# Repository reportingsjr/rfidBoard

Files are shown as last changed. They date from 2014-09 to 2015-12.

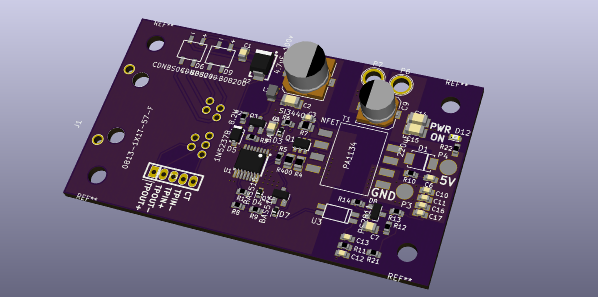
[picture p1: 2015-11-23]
hardware/POEstamp/POEstamp_3d_tilt.png

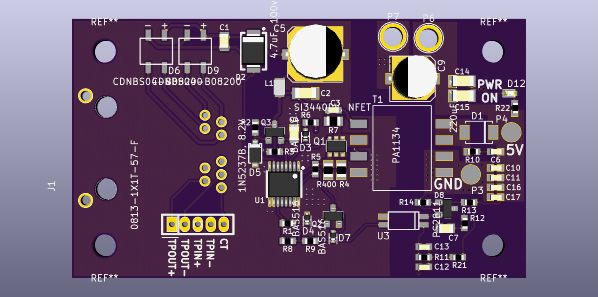
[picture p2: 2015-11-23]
hardware/POEstamp/POEstamp_3d_flat.png

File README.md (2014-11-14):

General
=========
This repository has the source for a PCB that uses Power over Ethernet (PoE) to power an STM32F103 microcontroller. It has a 10mbit ethernet MAC/PHY and  3.3V (.6A, 2W) and 12V (.5A, 6W) supplies fed from a 5V (1.8A, 9W) power rail. This gives this board the capability to provide power and control for quite a few different peripherals. The first use of the circuit boards and software in this repository is to provide a lower cost and more versatile RFID based entry method for a local hackerspace, Hive13.

In this repository you will currently find two main sections: hardware, and software. The hardware section contains the KiCad files for the PoE (power over ethernet)/micro board and the rfid transceiver board (rfidBoad). The software section contains the software/firmware for the stm32f103 to support the wanted functionality (currently ethernet comms and rfid/access control).
RFID/NFC board with ethernet+PoE with numerous I/Os.

Hardware
=========

The hardware consists of two separate boards: rfidBoard and PoE. rfidBoard is simply an rfid transceiver and antenna. PoE has an STM32F103 microcontroller which is connected to a 10mbit ethernet MAC/PHY. It alsohas a power over ethernet supply that provides 5V@1.8A total. This 5 volt supply provides power for a 3.3V supply and a 12V supply. The 3.3V supply is meant for powering ICs and other electronics while the 12V supply is meant for providing power to electronic door latches (solenoids).

rfid antenna
ST Micro's antenna.exe (can be found with google) was used to calculate the antenna size for an approximately 430nH antenna. A similar antenna of different shapes can be created by using the equations in the paper "Simple Accurate Expressions for Planar Spiral Inductances" (DOI 10.1109/4.792620). The parameters I used in antenna.exe are as follows: 2 turns, 8 segments, 1mm wide conductor, 0.25mm spacing between conductors, 35um conductor thickness, and 40mm by 40mm width and length.

Software
========
There is no software or firmware set up or written yet!
It will consist of a TCP/IP stack, an RFID stack, and a user access stack.

programs needed for compilation on fedora:
sudo yum install arm-none-eabi-gcc-cs arm-none-eabi-newlib scons

To program the board an STLINK v2 programmer is needed as well as stlink (on linux).

When cloning from git cd in to software/libopencm3 and run:
`git submodule init`
`git submodule update`

To flash the board with gdb and an st-link device:
In a separate terminal run the st-link server `st-util -1`
In another terminal run `arm-none-eabi-gdb firmware.elf`
Then in gdb run `tar ext :4242`, `load`, and finally either `continue` or `run`.

Datasheets
========
The datasheets directory contains some datasheets for different chips on board.
Currently it only contains STM32 microcontroller stuff.
They are large and don't fit well in to a git repository, but it helps keep
everything together and makes things easier to investigate down the line.

Notes and Issues
=========
* TODO: Add fuses on to POE board to protect circuitry.
* Several of the components in the PoE circuitry get WAY too hot.
* C5 (4.7uF cap on the PoE input) should have the negative pin connected to  GNDA/Pout rather than VPortN.
* ~~The 12V power supply current rating pretty much maxes out what the PoE can theoretically supply. Probably should derate the 12V supply quite a lot. This means that the 3.3V, 5V, and 12V will interfere with each other which is bad.~~ Updated current rating to 500mA which provides an ok margin for total power.
* ~~D1 may need to be unidirectional. The part specified in the BOM is currently bidirectional.~~ D1 should be a schottky!
* D2 is actually a zener, not a schottky as currently shown.
* *The footprint for U1 (LTC4267) is undersized.*

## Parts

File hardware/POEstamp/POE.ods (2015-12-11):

Reference | Value | Footprint | Datasheet | Vend1 | Vend1Id
U1 | LTC4267-3 | IPC7351-Nominal:SOP63P600X175-16 | https://cds.linear.com/docs/en/datasheet/4267fc.pdf | Digikey | LTC4267CGN-3#PBF-ND
C5 | 4.7uF, 100v | rfid:EEE-2AA4R7UP | http://media.digikey.com/pdf/Data%20Sheets/Panasonic%20Capacitors%20PDFs/EEE_S_A.pdf | Digikey | PCE3972CT-ND
C1 | 0.1uF, 100V, x7r | IPC7351-Nominal:CAPC2012X95 | https://media.digikey.com/pdf/Data%20Sheets/Samsung%20PDFs/CL21B104KCC5PNC_Spec.pdf | digikey | 1276-2447-1-ND
L1 | 3.3uH | IPC7351-Nominal:INDC2012X130 | https://product.tdk.com/info/en/catalog/datasheets/inductor_commercial_decoupling_mlz2012_en.pdf | Digikey | 445-6394-1-ND | FBMH1608HM601-T
C2 | 1uF, 100v | IPC7351-Nominal:CAPC3216X180 | http://ds.yuden.co.jp/TYCOMPAS/ut/detail.do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 | Digikey | 587-1777-1-ND
C4 | 4.7uF, 10v | IPC7351-Nominal:CAPC2012X135 | http://www.samsungsem.com/kr/support/product-search/mlcc/CL21A475KPFNNNE.jsp | Digikey | 1276-1259-1-ND | 490-3335-1-ND
D5 | 1N5237B, 8.2v | rfid:SOD-123 | http://www.diodes.com/_files/datasheets/ds18004.pdf | Digikey | BZT52C8V2-FDICT-ND
R2 | 220K | IPC7351-Nominal:RESC1608X55 | http://industrial.panasonic.com/www-cgi/jvcr13pz.cgi?E+PZ+3+AOA0002+ERJ3EKF2203V+7+WW | Digikey | P220KHCT-ND
R3 | 220K | IPC7351-Nominal:RESC1608X55 | http://industrial.panasonic.com/www-cgi/jvcr13pz.cgi?E+PZ+3+AOA0002+ERJ3EKF2203V+7+WW | Digikey | P220KHCT-ND
D3 | BAS516 | rfid:SOD-523 | http://www.nxp.com/documents/data_sheet/BAS16_SER.pdf | Digikey | 568-1603-1-ND
R6 | 510R | IPC7351-Nominal:RESC1608X55 | http://industrial.panasonic.com/www-cgi/jvcr13pz.cgi?E+PZ+3+AOA0002+ERJ3EKF5100V+7+WW | Digikey | P510HCT-ND
C3 | 68pF, 200v | IPC7351-Nominal:CAPC1608X87 | http://www.kemet.com/docfinder?Partnumber=C0603C680J2GACTU | Digikey | 399-10054-1-ND
R7 | 100R, 1/8w | IPC7351-Nominal:RESC2012X70 | http://industrial.panasonic.com/www-cgi/jvcr13pz.cgi?E+PZ+3+AOA0002+ERJ6ENF1000V+7+WW | Digikey | P100CCT-ND
T1 | PA1134 | rfid:PA1134 | http://productfinder.pulseeng.com/products/datasheets/SPM2007_55.pdf | Digikey | 553-1982-1-ND
R4 | 0.250R | IPC7351-Nominal:RESC2013X65 | http://www.seielect.com/catalog/SEI-CSR_CSRN.pdf | Digikey | CSR0805FKR250CT-ND
R400 | 0.250R | IPC7351-Nominal:RESC2013X65 | http://www.seielect.com/catalog/SEI-CSR_CSRN.pdf | Digikey | CSR0805FKR250CT-ND
R5 | 4.7K | IPC7351-Nominal:RESC1608X55 | http://www.te.com/commerce/DocumentDelivery/DDEController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 | Digikey | A106050CT-ND
D7 | BAS516 | rfid:SOD-523 | http://www.nxp.com/documents/data_sheet/BAS16_SER.pdf | Digikey | 568-1603-1-ND
D4 | BAS516 | rfid:SOD-523 | http://www.nxp.com/documents/data_sheet/BAS16_SER.pdf | Digikey | 568-1603-1-ND
R1 | 10k | IPC7351-Nominal:RESC1608X55 | http://industrial.panasonic.com/www-cgi/jvcr13pz.cgi?E+PZ+3+AOA0002+ERJ3EKF1002V+7+WW | Digikey | P10.0KHCT-ND
R8 | 100k | IPC7351-Nominal:RESC1608X55 | http://industrial.panasonic.com/www-cgi/jvcr13pz.cgi?E+PZ+3+AOA0002+ERJ3EKF1003V+7+WW | Digikey | P100KHCT-ND
R9 | 6.8k | IPC7351-Nominal:RESC1608X55 | http://industrial.panasonic.com/www-cgi/jvcr13pz.cgi?E+PZ+3+AOA0002+ERJ3EKF6801V+7+WW | Digikey | P6.80KHCT-ND
U3 | PS2811 | rfid:SSOP-4 | http://www.cel.com/pdf/datasheets/ps2811.pdf | Digikey | PS2811-1ACT-ND
D1 | PMEG3050EP | rfid:SOD-128 | http://www.nxp.com/documents/data_sheet/PMEG3050EP.pdf | Digikey | 568-6753-1-ND
R10 | 10R | IPC7351-Nominal:RESC1608X55 | http://industrial.panasonic.com/www-cgi/jvcr13pz.cgi?E+PZ+3+AOA0001+ERJ3GEYJ100V+7+WW | Digikey | P10GCT-ND
C6 | 470pF | IPC7351-Nominal:CAPC1608X90 | http://www.samsungsem.com/kr/support/product-search/mlcc/CL10B471KB8NNNC.jsp | Digikey | 1276-1094-1-ND
C14 | 100uF, 6.3v, x5r | IPC7351-Nominal:CAPC3216X180 | http://capacitoredge.kemet.com/capedge2/DataSheet?pn=C1206C107M9PACTU | Digikey | 399-5620-1-ND | CL31A107MQHNNNE
C9 | 220uF, 6.3v | rfid:EEE-FK0J221P | http://industrial.panasonic.com/www-cgi/jvcr13pz.cgi?E+PZ+3+ABA0120+EEEFK0J221P+7+WW | Digikey | PCE3766CT-ND
C15 | 100uF, 6.3v, x5r | IPC7351-Nominal:CAPC3216X180 | http://capacitoredge.kemet.com/capedge2/DataSheet?pn=C1206C107M9PACTU | Digikey | 399-5620-1-ND | CL31A107MQHNNNE
R14 | 33.2k | IPC7351-Nominal:RESC1608X55 | http://industrial.panasonic.com/www-cgi/jvcr13pz.cgi?E+PZ+3+AOA0002+ERJ3EKF3322V+7+WW | Digikey | P33.2KHCT-ND
R13 | 100k, 1% | IPC7351-Nominal:RESC1608X55 | http://industrial.panasonic.com/www-cgi/jvcr13pz.cgi?E+PZ+3+AOA0002+ERJ3EKF1003V+7+WW | Digikey | P100KHCT-ND
R11 | 1k | IPC7351-Nominal:RESC1608X55 | http://www.te.com/commerce/DocumentDelivery/DDEController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 | Digikey | A106049CT-ND
C12 | 1uF | IPC7351-Nominal:CAPC1608X90 | http://www.samsungsem.com/kr/support/product-search/mlcc/CL10F105ZP8NNNC.jsp | Digikey | 1276-1041-1-ND
C13 | 33nF | IPC7351-Nominal:CAPC1608X95 | https://product.tdk.com/info/en/catalog/spec/mlccspec_commercial_general_midvoltage_en.pdf | Digikey | 445-5093-1-ND
C7 | 27nF | IPC7351-Nominal:CAPC2012X88 | http://www.yageo.com/documents/recent/UPY-GPHC_X7R_6.3V-to-50V-v12.pdf | Digikey | 311-1139-1-ND | CL10B273KB8SFNC
R12 | 47k | IPC7351-Nominal:RESC1608X55 | http://industrial.panasonic.com/www-cgi/jvcr13pz.cgi?E+PZ+3+AOA0002+ERJ3EKF4702V+7+WW | Digikey | P47.0KHCT-ND
P4 | +5V | Measurement_Points:Measurement_Point_Round-SMD-Pad_Big
P3 | GND | Measurement_Points:Measurement_Point_Round-SMD-Pad_Big
J1 | 0813-1X1T-57-F | rfid:0813-1X1T-57-F | http://belfuse.com/pdfs/0813-1X1T-57-F.pdf | Digikey | 507-1421-ND
R22 | 2.8k | IPC7351-Nominal:RESC1608X55 | http://www.yageo.com/NewPortal/yageodocoutput?fileName=/pdf/R-Chip/PYu-RC_Group_51_RoHS_L_3.pdf | Digikey | 311-2.80KHRCT-ND
D8 | TLV431 | smd-semi:SOT-23 | http://www.diodes.com/_files/datasheets/TLV431.pdf | Digikey | TLV431AFTACT-ND
D9 | CDNBS04-B08200 | rfid:CDNBS04
D6 | CDNBS04-B08200 | rfid:CDNBS04 | http://www.bourns.com/docs/Product-Datasheets/CDNBS04-B08200_B08800.pdf | Digikey | CDNBS04-B08200CT-ND
Q1 | SI3440DV, NFET | rfid:TSOP-6 | http://www.vishay.com/docs/72380/72380.pdf | Digikey | SI3440DV-T1-E3CT-ND
D2 | SMAJ58A | IPC7351-Nominal:DIOM5436X265 | http://www.littelfuse.com/~/media/electronics/datasheets/tvs_diodes/littelfuse_tvs_diode_smaj_datasheet.pdf.pdf | Digikey | SMAJ58ALFCT-ND
C8 | 2.8nF, 250VAC, YCAP | IPC7351-Nominal:CAPC4532X150 | http://psearch.murata.com/capacitor/product/GA343QR7GD222KW01%23.pdf | Digikey | 490-3492-1-ND
C10 | 100nF | IPC7351-Nominal:CAPC1608X90 | http://www.yageo.com/documents/recent/UPY-GPHC_Y5V_6.3V-to-50V_5_revised.pdf | Digikey | 311-1343-1-ND
C11 | 100nF | IPC7351-Nominal:CAPC1608X90 | http://www.yageo.com/documents/recent/UPY-GPHC_Y5V_6.3V-to-50V_5_revised.pdf | Digikey | 311-1343-1-ND
C16 | 1uF | IPC7351-Nominal:CAPC1608X90 | http://search.murata.co.jp/Ceramy/image/img/A01X/G101/ENG/GRM188R61E105KA12-01.pdf | Digikey | 490-3897-1-ND
C17 | 1uF | IPC7351-Nominal:CAPC1608X90 | http://search.murata.co.jp/Ceramy/image/img/A01X/G101/ENG/GRM188R61E105KA12-01.pdf | Digikey | 490-3897-1-ND
Q3 | MMBTA42 | smd-semi:SOT-23 | http://www.diodes.com/_files/datasheets/ds30062.pdf | Digikey | MMBTA42-FDICT-ND
Q2 | 2N7002 | smd-semi:SOT-23 | http://www.diodes.com/_files/datasheets/ds11303.pdf | Digikey | 2N7002-FDICT-ND
P5 | CONN_01X05 | conn-2mm:CONN-2MM-F-1x5
P6 | 5Vout | Connect:1pin
P7 | GNDout | Connect:1pin
R21 | 470R | IPC7351-Nominal:RESC1608X55 | http://industrial.panasonic.com/www-cgi/jvcr13pz.cgi?E+PZ+3+AOA0002+ERJ3EKF4700V+7+WW | Digikey | P470HCT-ND
D12 | 5V LED | LEDs:LED-0603 | http://www.osram-os.com/Graphics/XPic9/00128783_0.pdf | Digikey | 475-1409-1-ND

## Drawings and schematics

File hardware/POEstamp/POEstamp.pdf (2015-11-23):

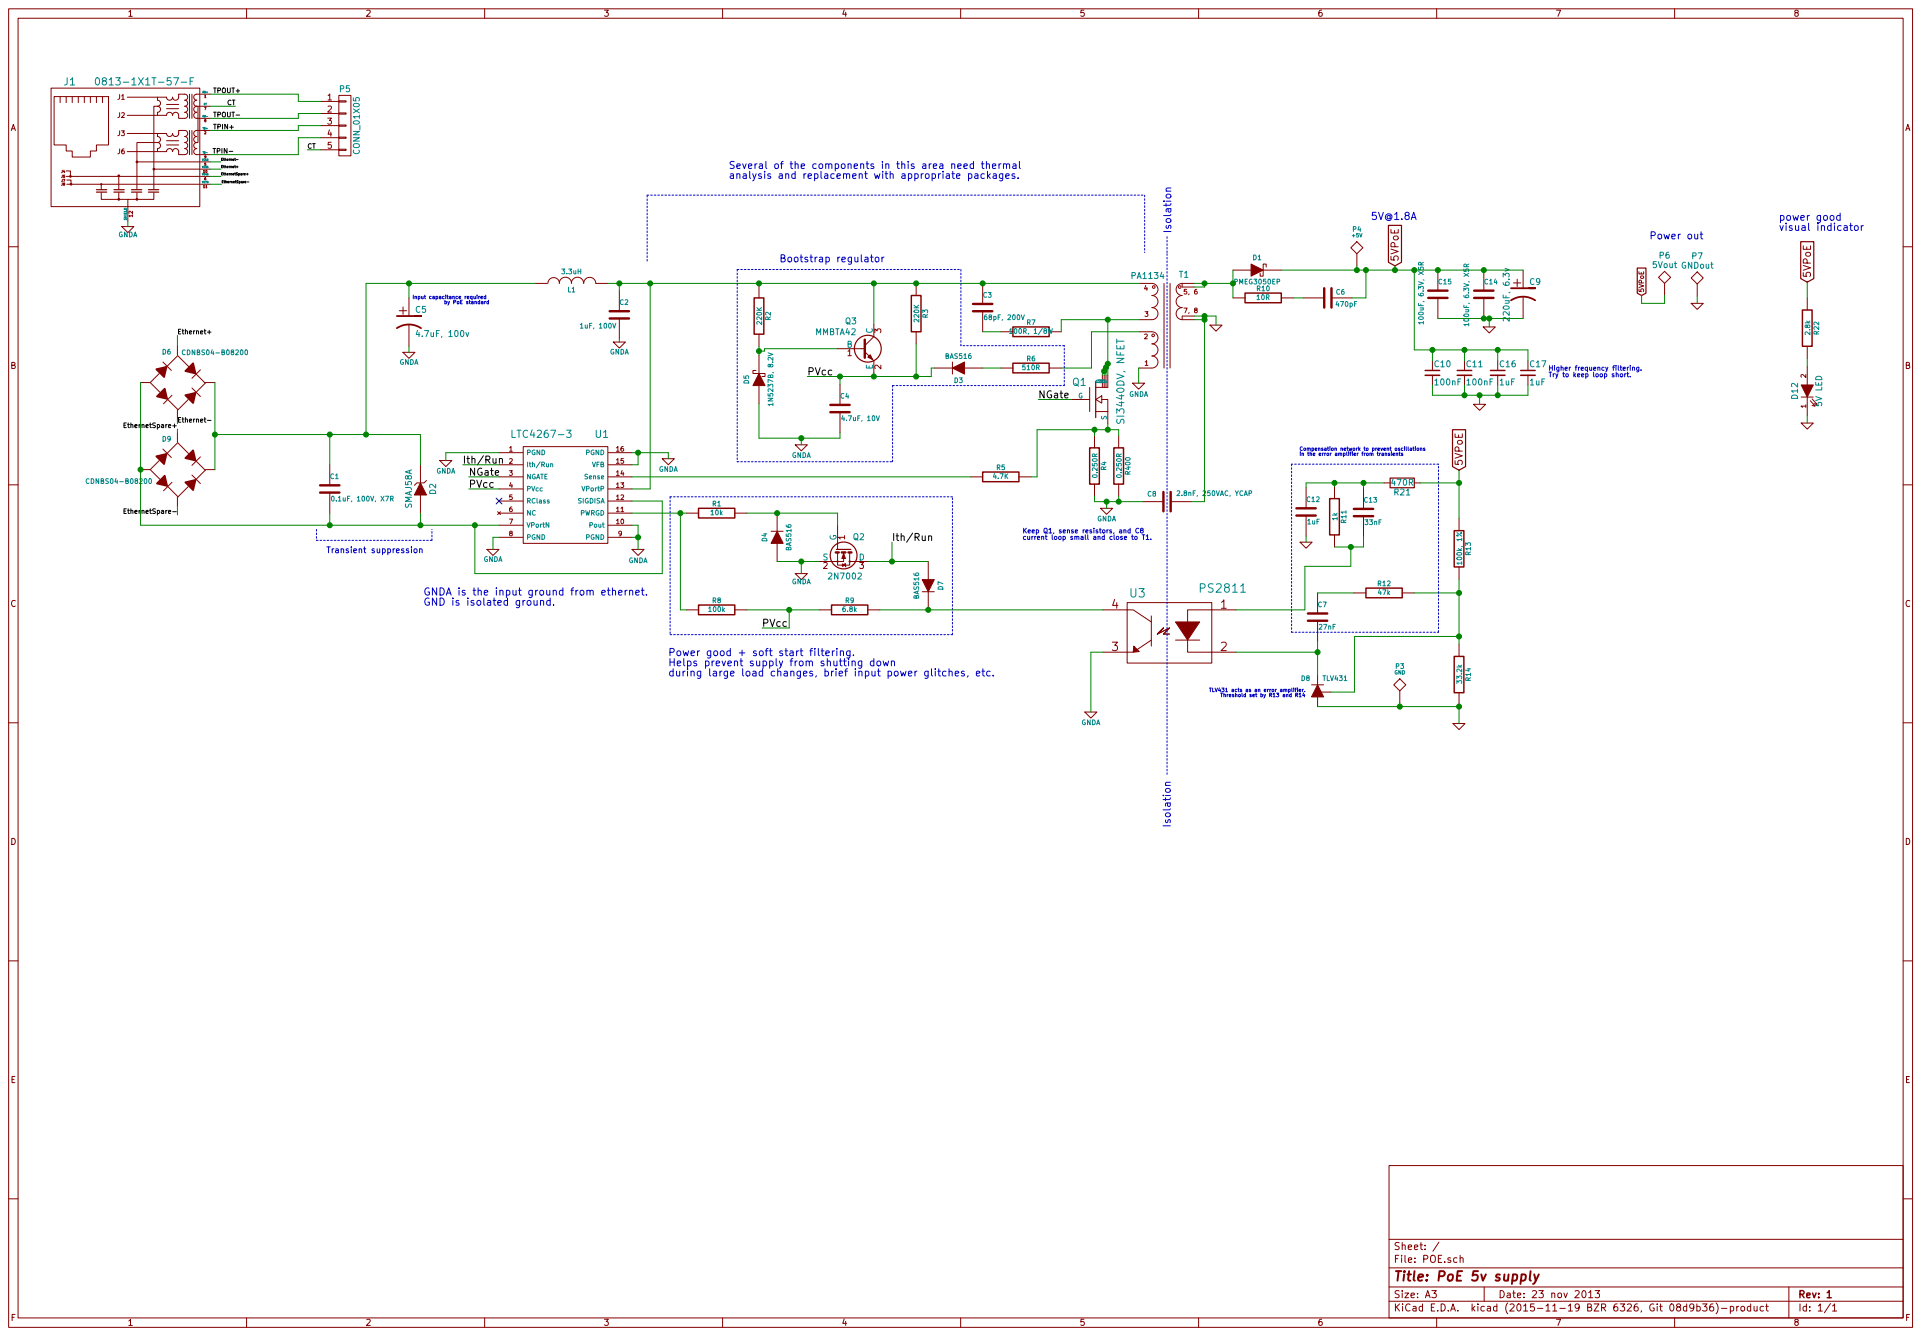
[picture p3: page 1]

470R Several of the components in this area need thermal

Input capacitance required by PoE standard

Higher frequency filtering. Try to keep loop short. B

in the error amplifier from transients Ith/Run

TLV431 acts as an error amplifier. Threshold set by R13 and R14Compensation network to prevent oscillations

Keep Q1, sense resistors, and C8 current loop small and close to T1. Power good + soft start filtering.

Helps prevent supply from shutting down

File: POE.sch Sheet: /
Id: 1/1 Title: PoE 5v supply

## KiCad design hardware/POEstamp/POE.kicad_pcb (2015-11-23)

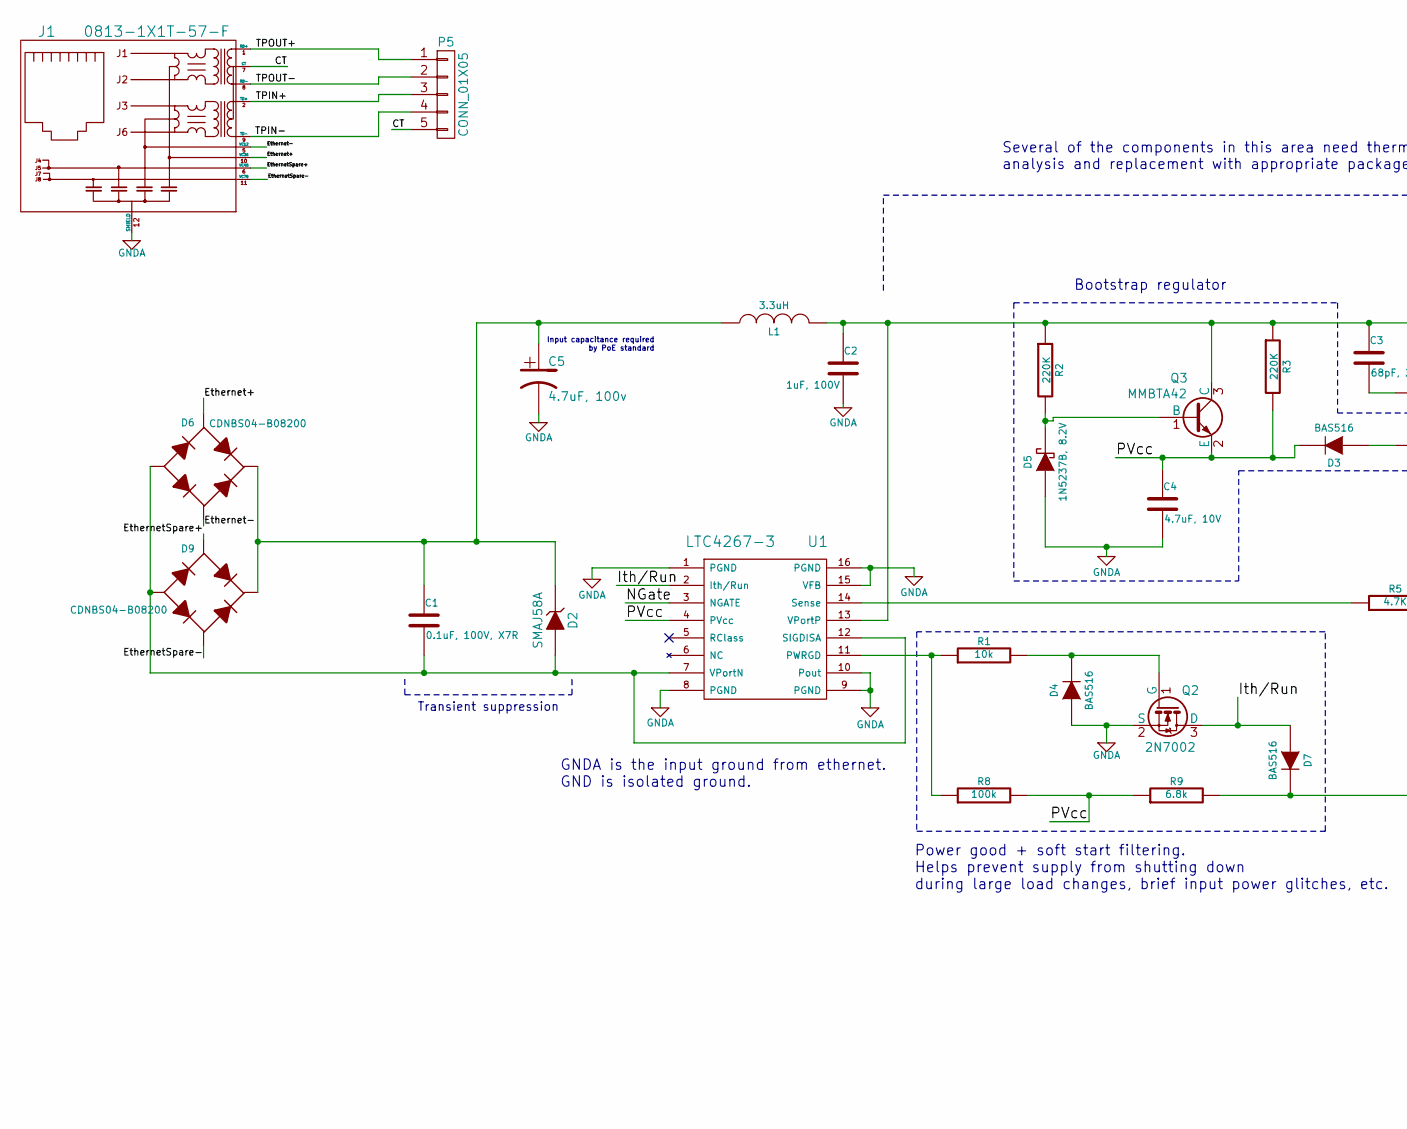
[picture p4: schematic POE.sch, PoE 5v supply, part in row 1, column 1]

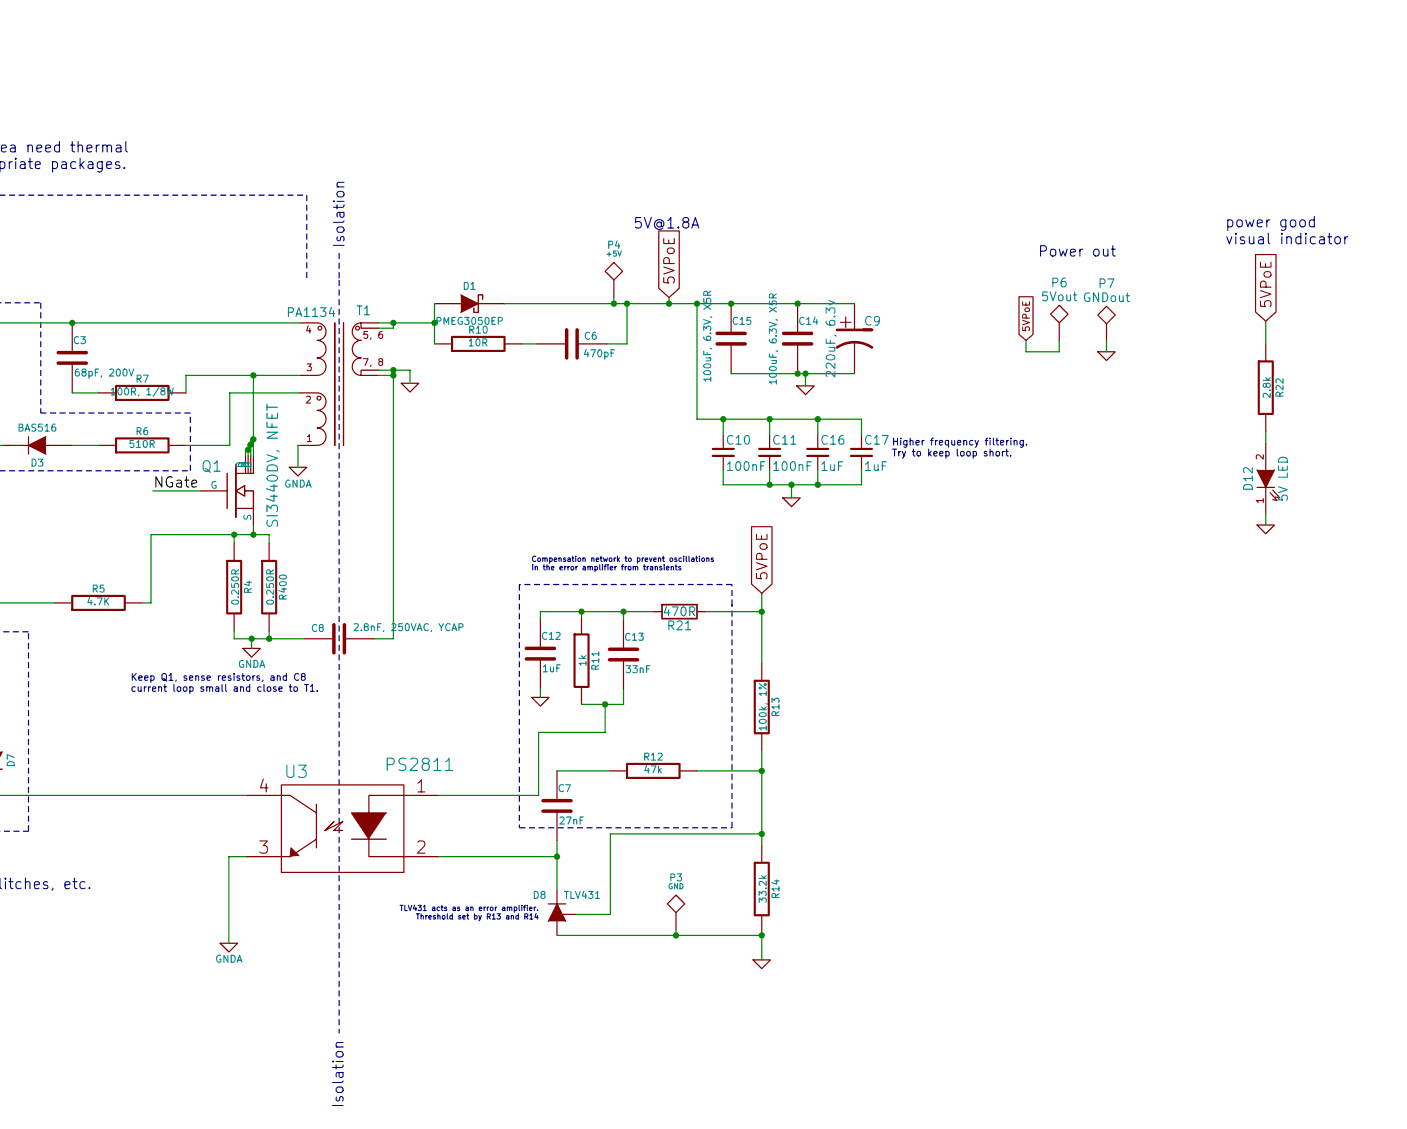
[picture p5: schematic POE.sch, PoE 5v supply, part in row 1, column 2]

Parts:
C1: 0.1uF, 100V, X7R; CAPC2012X95
C2: 1uF, 100V; CAPC3216X180
C3: 68pF, 200V; CAPC1608X87
C4: 4.7uF, 10V; CAPC2012X135
C5: 4.7uF, 100v; EEE-2AA4R7UP
C6: 470pF; CAPC1608X90
C7: 27nF; CAPC2012X88
C8: 2.8nF, 250VAC, YCAP; CAPC4532X150
C9: 220uF, 6.3v; EEE-FK0J221P
C10, C11: 100nF; CAPC1608X90
C12, C16, C17: 1uF; CAPC1608X90
C13: 33nF; CAPC1608X95
C14, C15: 100uF, 6.3V, X5R; CAPC3216X180
D1: PMEG3050EP; SOD-128
D2: SMAJ58A; DIOM5436X265
D3, D4, D7: BAS516; SOD-523
D5: 1N5237B, 8.2V; SOD-123
D6, D9: CDNBS04-B08200; CDNBS04
D8: TLV431; SOT-23
D12: 5V LED; LED-0603
J1: 0813-1X1T-57-F
L1: 3.3uH; INDC2012X130
P3: GND; Measurement_Point_Round-SMD-Pad_Big
P4: +5V; Measurement_Point_Round-SMD-Pad_Big
P5: CONN_01X05; CONN-2MM-F-1x5
P6: 5Vout; 1pin
P7: GNDout; 1pin
Q1: SI3440DV, NFET; TSOP-6
Q2: 2N7002; SOT-23
Q3: MMBTA42; SOT-23
R1: 10k; RESC1608X55
R2, R3: 220K; RESC1608X55
R4, R400: 0.250R; RESC2013X65
R5: 4.7K; RESC1608X55
R6: 510R; RESC1608X55
R7: 100R, 1/8W; RESC2012X70
R8: 100k; RESC1608X55
R9: 6.8k; RESC1608X55
R10: 10R; RESC1608X55
R11: 1k; RESC1608X55
R12: 47k; RESC1608X55
R13: 100k, 1%; RESC1608X55
R14: 33.2k; RESC1608X55
R21: 470R; RESC1608X55
R22: 2.8k; RESC1608X55
T1: PA1134
U1: LTC4267-3; SOP63P600X175-16
U3: PS2811; SSOP-4

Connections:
5VPoE: C6.1, C9.1, C10.1, C11.1, C14.1, C15.1, C16.1, C17.1, D1.2 (K), P4.1, P6.1, R13.1, R21.1, R22.1
/CT: J1.7 (CT), P5.5
/Ethernet+: D6.3, J1.10 (VC36)
/Ethernet-: D6.2, J1.5 (VC12)
/EthernetSpare+: D9.3, J1.6 (VC45)
/EthernetSpare-: D9.2, J1.11 (VC78)
/Ith/Run: D7.1 (A), Q2.3 (D), U1.2 (Ith/Run)
/NGate: Q1.3 (G), U1.3 (NGATE)
/PVcc: C4.1, D3.2 (K), Q3.2 (E), R3.2, R8.2, R9.1, U1.4 (PVcc)
/TPIN+: J1.2 (TD+), P5.3
/TPIN-: J1.9 (TD-), P5.4
/TPOUT+: J1.1 (RD+), P5.1
/TPOUT-: J1.8 (RD-), P5.2
GND: C8.1, C9.2, C10.2, C11.2, C12.2, C14.2, C15.2, C16.2, C17.2, D8.3 (A), D12.1 (K), P3.1, P7.1, R14.2, T1.7, T1.8
GNDA: C2.2, C4.2, C5.2, C8.2, D4.1 (A), D5.1 (A), J1.12 (SHIELD), Q2.2 (S), R4.2, R400.2, T1.1, U1.1 (PGND), U1.8 (PGND), U1.9 (PGND), U1.10 (Pout), U1.15 (VFB), U1.16 (PGND), U3.3
unnamed: C1.1, C5.1, D2.1 (K), D6.1 (+), D9.1 (+), L1.1
unnamed: C1.2, D2.2 (A), D6.4 (-), D9.4 (-), U1.7 (VPortN), U1.12 (SIGDISA)
unnamed: C2.1, C3.1, L1.2, Q3.3 (C), R2.1, R3.1, T1.4, U1.13 (VPortP)
unnamed: C3.2, R7.1
unnamed: C6.2, R10.2
unnamed: C7.1, R12.1
unnamed: C7.2, D8.2 (K), U3.2
unnamed: C12.1, C13.1, R11.1, R21.2
unnamed: C13.2, R11.2, U3.1
unnamed: D1.1 (A), R10.1, T1.5, T1.6
unnamed: D3.1 (A), R6.1
unnamed: D4.2 (K), Q2.1 (G), R1.2
unnamed: D5.2 (K), Q3.1 (B), R2.2
unnamed: D7.2 (K), R9.2, U3.4
unnamed: D8.1 (ref), R12.2, R13.2, R14.1
unnamed: D12.2 (A), R22.2
unnamed: Q1.1 (D), Q1.2 (D), Q1.5 (D), Q1.6 (D), R7.2, T1.3
unnamed: Q1.4 (S), R4.1, R5.2, R400.1
unnamed: R1.1, R8.1, U1.11 (PWRGD)
unnamed: R5.1, U1.14 (Sense)
unnamed: R6.2, T1.2

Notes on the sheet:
GNDA is the input ground from ethernet. GND is isolated ground.
5V@1.8A
power good visual indicator
Keep Q1, sense resistors, and C8 current loop small and close to T1.
Power good + soft start filtering. Helps prevent supply from shutting down during large load changes, brief input power glitches, etc.
Isolation
Transient suppression
Input capacitance required by PoE standard
TLV431 acts as an error amplifier. Threshold set by R13 and R14
Compensation network to prevent oscillations in the error amplifier from transients
Bootstrap regulator
Higher frequency filtering. Try to keep loop short.
Power out
Several of the components in this area need thermal analysis and replacement with appropriate packages.

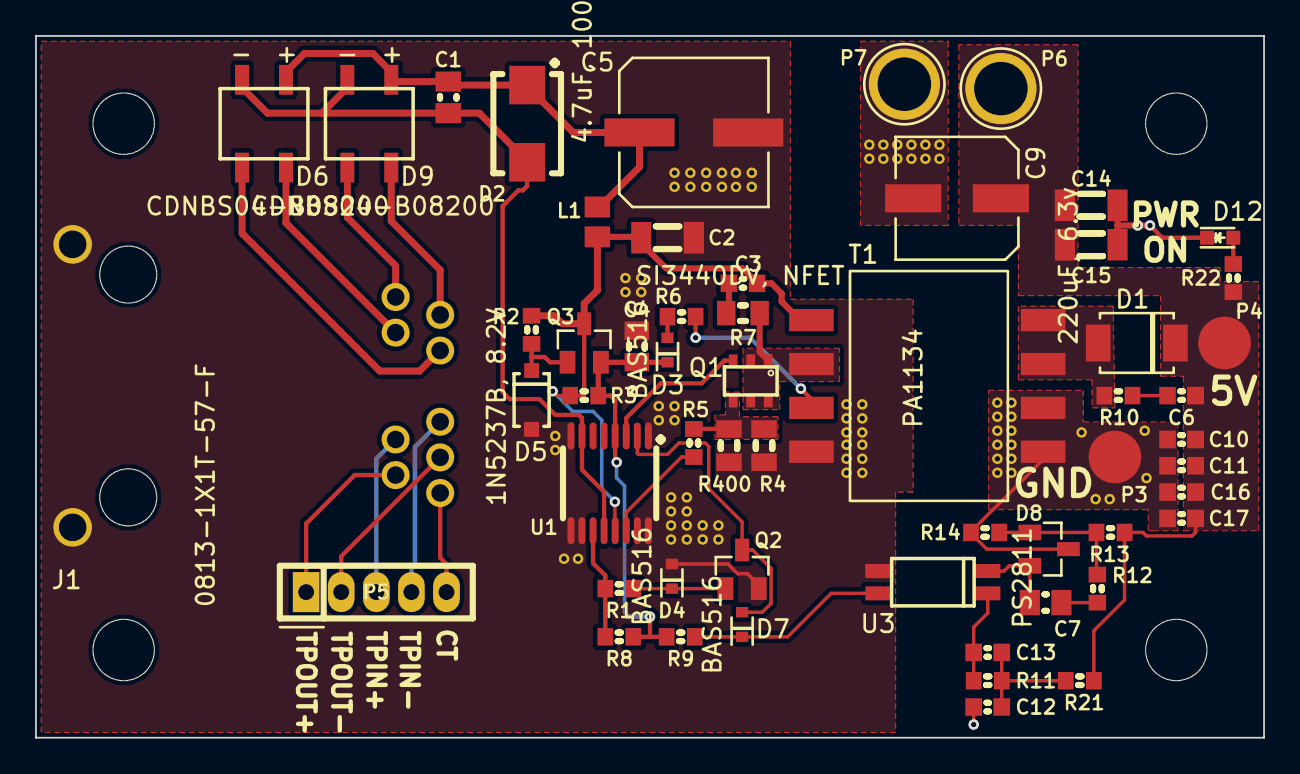
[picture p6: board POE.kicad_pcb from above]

Board: 2 copper layers, 70.0 x 40.0 mm, 57 parts (1 on the bottom side), 36 nets.

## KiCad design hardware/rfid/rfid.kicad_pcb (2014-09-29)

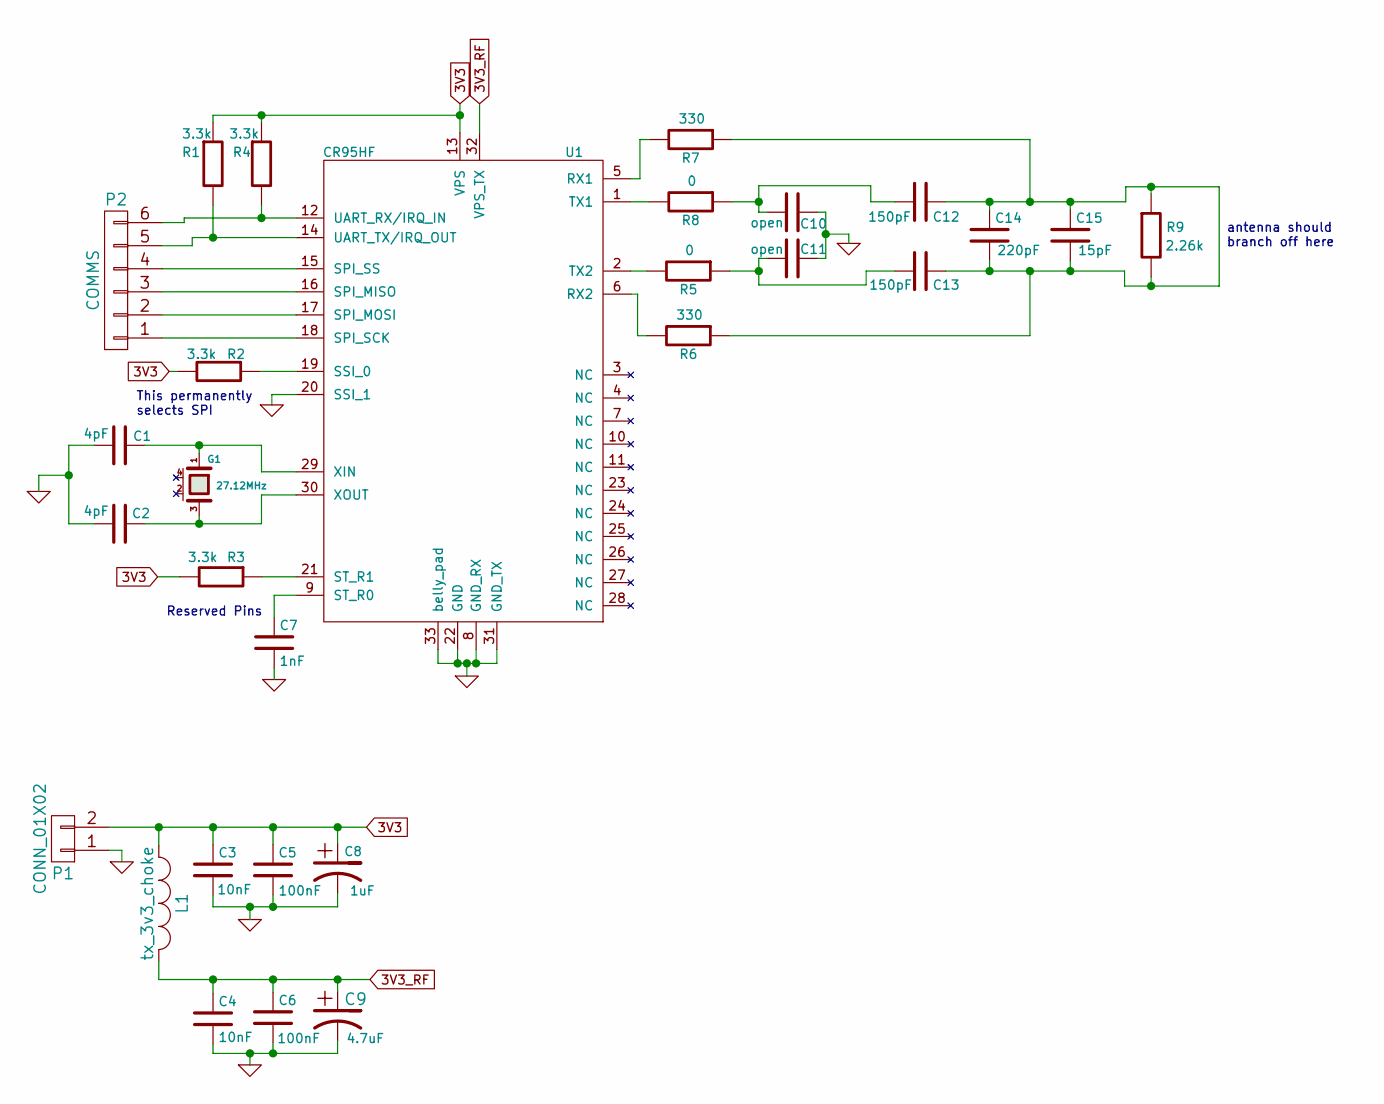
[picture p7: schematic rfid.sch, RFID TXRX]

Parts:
C1, C2: 4pF; SMD-0603
C3, C4: 10nF; SMD-0603
C5, C6: 100nF; SMD-0603
C7: 1nF; SMD-0603
C8: 1uF; SMD-0603
C9: 4.7uF; SMD-0805
C10, C11: open; SMD-0603
C12, C13: 150pF; SMD-0603
C14: 220pF; SMD-0603
C15: 15pF; SMD-0603
G1: 27.12MHz; 2x1.6_crystal
L1: tx_3v3_choke; SMD-0603
P1: CONN_01X02; JST_PH_2pin_side
P2: COMMS; JST_PH_6pin
R1, R2, R3, R4: 3.3k; SMD-0603
R5, R8: 0; SMD-0603
R6, R7: 330; SMD-0603
R9: 2.26k; SMD-0603
U1: CR95HF; QFN-32-1EP

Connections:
3V3: C3.1, C5.1, C8.1, L1.1, P1.2, R1.1, R2.2, R3.2, R4.1, U1.13 (VPS)
3V3_RF: C4.1, C6.1, C9.1, L1.2, U1.32 (VPS_TX)
GND: C1.2, C2.2, C3.2, C4.2, C5.2, C6.2, C7.2, C8.2, C9.2, C10.1, C11.1, P1.1, U1.8 (GND_RX), U1.20 (SSI_1), U1.22 (GND), U1.31 (GND_TX), U1.33 (belly_pad)
unnamed: C1.1, G1.1, U1.29 (XIN)
unnamed: C2.1, G1.3, U1.30 (XOUT)
unnamed: C7.1, U1.9 (ST_R0)
unnamed: C10.2, C12.2, R8.1
unnamed: C11.2, C13.2, R5.1
unnamed: C12.1, C13.1, C14.1, C14.2, C15.1, C15.2, R6.1, R7.1, R9.1, R9.2
unnamed: P2.1, U1.18 (SPI_SCK)
unnamed: P2.2, U1.17 (SPI_MOSI)
unnamed: P2.3, U1.16 (SPI_MISO)
unnamed: P2.4, U1.15 (SPI_SS)
unnamed: P2.5, R1.2, U1.14 (UART_TX/IRQ_OUT)
unnamed: P2.6, R4.2, U1.12 (UART_RX/IRQ_IN)
unnamed: R2.1, U1.19 (SSI_0)
unnamed: R3.1, U1.21 (ST_R1)
unnamed: R5.2, U1.2 (TX2)
unnamed: R6.2, U1.6 (RX2)
unnamed: R7.2, U1.5 (RX1)
unnamed: R8.2, U1.1 (TX1)

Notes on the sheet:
Reserved Pins
This permanently selects SPI
antenna should branch off here

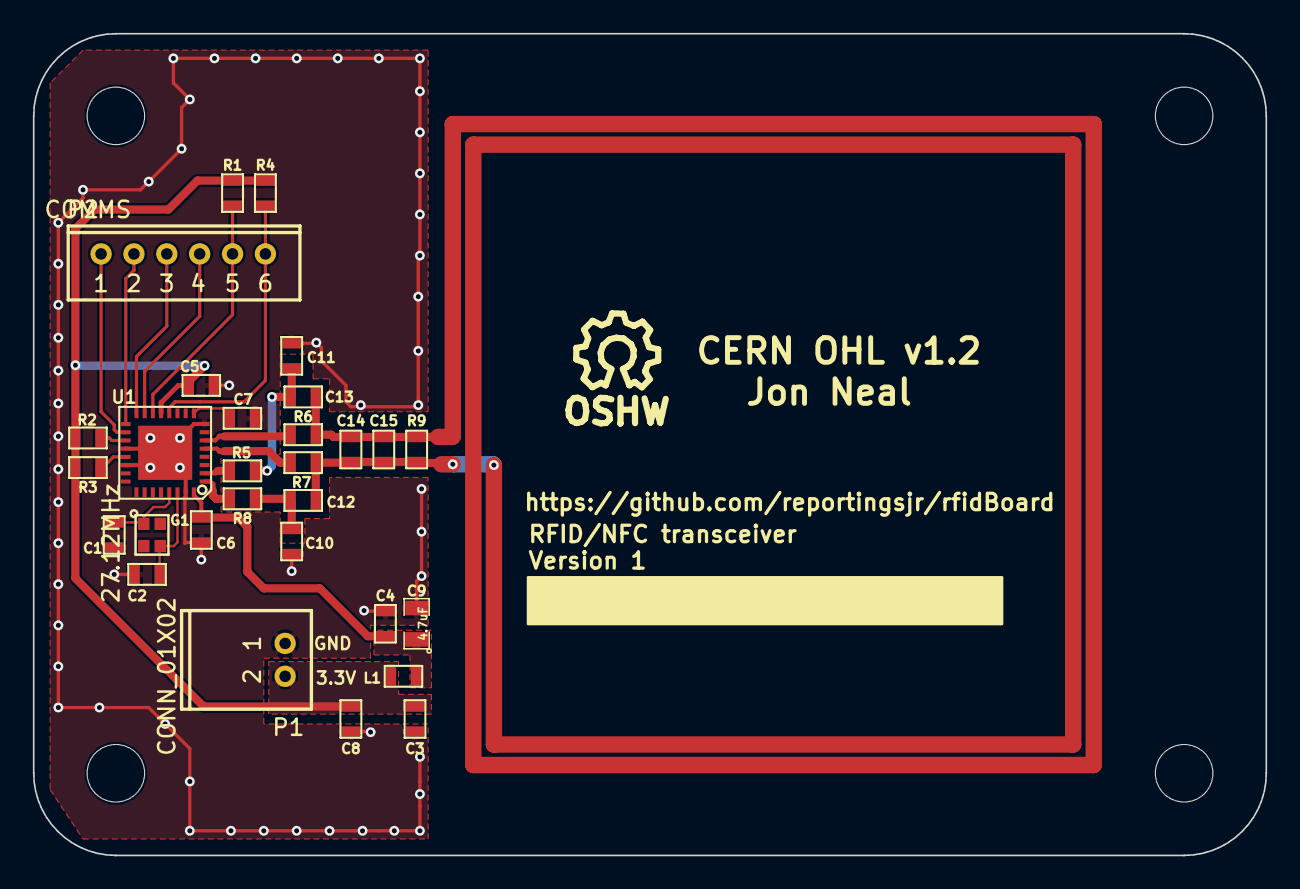
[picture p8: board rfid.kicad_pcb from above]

Board: 2 copper layers, 75.0 x 50.0 mm, 34 parts (0 on the bottom side), 21 nets.

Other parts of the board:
MH: MountingHole_3-5mm_RevA_Date21Jun2010; MountingHole_3-5mm
MH#2, MH#3, MH#4: MountingHole_3-5mm_RevA_Date21Jun2010; MountingHole_3-5mm
SYM: Symbol_OSHW-Logo_SilkScreen_07Jul2012; Symbol_OSHW-Logo_SilkScreen

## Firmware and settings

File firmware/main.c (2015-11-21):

/*
    ChibiOS/RT - Copyright (C) 2006-2013 Giovanni Di Sirio

    Licensed under the Apache License, Version 2.0 (the "License");
    you may not use this file except in compliance with the License.
    You may obtain a copy of the License at

        http://www.apache.org/licenses/LICENSE-2.0

    Unless required by applicable law or agreed to in writing, software
    distributed under the License is distributed on an "AS IS" BASIS,
    WITHOUT WARRANTIES OR CONDITIONS OF ANY KIND, either express or implied.
    See the License for the specific language governing permissions and
    limitations under the License.
*/

#include "ch.h"
#include "hal.h"
#include "halconf.h"
#include "cr95hf_driver.h"

static const EXTConfig extcfg = {
  {
    {EXT_CH_MODE_DISABLED, NULL},  
    {EXT_CH_MODE_DISABLED, NULL},
    {EXT_CH_MODE_DISABLED, NULL},
    {EXT_CH_MODE_DISABLED, NULL},
    {EXT_CH_MODE_DISABLED, NULL},
    {EXT_CH_MODE_DISABLED, NULL},
    {EXT_CH_MODE_DISABLED, NULL},
    {EXT_CH_MODE_DISABLED, NULL},
    {EXT_CH_MODE_DISABLED, NULL},
    {EXT_CH_MODE_FALLING_EDGE | EXT_MODE_GPIOA, cr95hfInterrupt},
    {EXT_CH_MODE_DISABLED, NULL}, 
    {EXT_CH_MODE_DISABLED, NULL},
    {EXT_CH_MODE_DISABLED, NULL},
    {EXT_CH_MODE_DISABLED, NULL},
    {EXT_CH_MODE_DISABLED, NULL},
    {EXT_CH_MODE_DISABLED, NULL}
  }
};

/*
 * Application entry point.
 */
int main(void) {

  /*
   * System initializations.
   * - HAL initialization, this also initializes the configured device drivers
   *   and performs the board-specific initializations.
   * - Kernel initialization, the main() function becomes a thread and the
   *   RTOS is active.
   */
  halInit();
  chSysInit();

  struct pin IRQ_OUT = {GPIOA, 10};
  struct pin IRQ_IN = {GPIOA, 11};
  
  //extStart(&EXTD1, &extcfg);
  //cr95hf_init(&IRQ_IN, &IRQ_OUT, GPIOA, GPIOA_SPI1NSS);
  //extChannelEnable(&EXTD1, (expchannel_t) 2);
 
  palSetPadMode(GPIOB, 8, PAL_MODE_OUTPUT_PUSHPULL);
  palClearPad(GPIOB, 8);

  //setProtocol();
  //ISO14443AAdjustRegisters();
  // removed during dev since it is annoying
  //tagCalibrate();
  idle();
  chThdSleep(TIME_INFINITE);
  
    return 0;
}

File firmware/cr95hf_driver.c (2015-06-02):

// STM CR95HF chibios driver
#include "cr95hf_driver.h"
#include "ch.h"
#include "hal.h"
#include "string.h"

uint8_t CR95HF_CMD = 0x00;
uint8_t CR95HF_POLL = 0x03;
uint8_t CR95HF_READ = 0x02;
uint8_t CR95HF_RESET = 0x01;

static struct pin IRQ_IN, IRQ_OUT;
static SPIConfig spicfg;

static thread_t *messageThread;

static mailbox_t cr95hfMailbox;
// 10 messages should be enough of a buffer
static msg_t cr95hfMailboxBuf[10];

static uint8_t rxbuf[255];
static uint8_t txbuf[255];

static uint8_t idleCommand[16];

// thread that watches for messages in a mailbox
// when the cr95hf sends a pulse on IRQ_OUT an interrupt is generated
// which reads the message the IC has and puts it in the mailbox.
// This thread infinitely loops and when it sees data parses it and
// calls the appropriate function.
static THD_WORKING_AREA(cr95hfMessageThreadWA, 512);
static THD_FUNCTION(cr95hfMessageThread, arg) {
  (void)arg;
  
  while (!chThdShouldTerminateX()) {
    chEvtWaitAnyTimeout((eventmask_t)1, TIME_INFINITE);
    spiAcquireBus(&SPID1);
    spiSelect(&SPID1);
    spiSend(&SPID1, 1, &CR95HF_READ);
    // get the response code
    spiReceive(&SPID1, sizeof(rxbuf), &rxbuf);
    spiUnselect(&SPID1);
    spiReleaseBus(&SPID1);
    chMBPost(&cr95hfMailbox, (msg_t)0x00, TIME_INFINITE);
    // clear variables before next loop
  }
}

// Initializes SPI and interrupt for the cr95hf IC.
// Sends initialize command and waits for the chip to start up.
void cr95hf_init(struct pin *IRQ_IN_temp,
                 struct pin *IRQ_OUT_temp,
                 ioportid_t spi_port,
                 uint16_t spi_select_pin) {
  memcpy(&IRQ_IN, IRQ_IN_temp, sizeof(IRQ_IN));
  memcpy(&IRQ_OUT, IRQ_OUT_temp, sizeof(IRQ_OUT));
  
  // initalize static arrays to all zeros
  memset(rxbuf, 0x00, sizeof(rxbuf));
  memset(rxbuf, 0x00, sizeof(txbuf));
  memset(idleCommand, 0x00, sizeof(idleCommand));

  chMBObjectInit(&cr95hfMailbox, cr95hfMailboxBuf, sizeof(cr95hfMailboxBuf)/sizeof(msg_t));

  spicfg = (SPIConfig) {
    NULL,
    spi_port,
    spi_select_pin,
    SPI_CR1_BR_2
  };
  spiStart(&SPID1, &spicfg);
  // send a reset command just in case the cr95hf hasn't been powered off
  spiSelect(&SPID1);
  spiSend(&SPID1, 1, &CR95HF_RESET);
  spiUnselect(&SPID1);

  // send idle command to start from known state
  // send wake up on IRQ_IN pin
  palSetPadMode(IRQ_OUT.port, IRQ_OUT.pin, PAL_MODE_INPUT);
  palSetPadMode(IRQ_IN.port, IRQ_IN.pin, PAL_MODE_OUTPUT_PUSHPULL);
  palSetPadMode(GPIOA, 1, PAL_MODE_OUTPUT_PUSHPULL);
  // Send a 20us pulse to wake up the CR95HF
  palClearPad(IRQ_IN.port, IRQ_IN.pin);
  // delay for 20 microseconds so the cr95hf sees it for sure
  // (this is double the minimum)
  chSysPolledDelayX(US2RTC(STM32_HCLK, 20));
  palSetPad(IRQ_IN.port, IRQ_IN.pin);
  // wait 10 ms to let the CR95HF set itself up
  chSysPolledDelayX(MS2RTC(STM32_HCLK, 10));
  
  //start the thread that watches for messages from the cr95hf
  messageThread = chThdCreateStatic(cr95hfMessageThreadWA, 
                                    sizeof(cr95hfMessageThreadWA), 
                                    NORMALPRIO, cr95hfMessageThread, NULL);
}

void setProtocol() {
  uint8_t command = 0x02; // protocol select
  uint8_t length  = 0x04; // 2 bytes of data
  uint8_t data[4] = {0x02, 0x00, 0x03, 0x00};
  msg_t message;
  
  spiAcquireBus(&SPID1);
  spiSelect(&SPID1);
  // send control byte for send command
  spiSend(&SPID1, 1, &CR95HF_CMD);
  spiSend(&SPID1, 1, &command);
  spiSend(&SPID1, 1, &length);
  spiSend(&SPID1, 4, &data);
  spiUnselect(&SPID1);
  spiReleaseBus(&SPID1);
  chMBFetch(&cr95hfMailbox, &message, TIME_INFINITE);
  if(rxbuf[0] == 0x00) {
    // everything went as planned
  } else if(rxbuf[0] == 0x82) {
    // invalid command length
  }
  memset(rxbuf, 0x00, sizeof(rxbuf));
}



// Echo is a special command since it does not require a data length to be sent.
// Sends 0x55 and expects to receive 0x55 back if SPI is working.
void echo() {
  uint8_t echo = 0x55;
  msg_t message;
  
  spiAcquireBus(&SPID1);
  spiSelect(&SPID1);
  spiSend(&SPID1, 1, &CR95HF_CMD);
  spiSend(&SPID1, 1, &echo);
  spiUnselect(&SPID1);
  // watch for a message here and when received parse the data
  spiReleaseBus(&SPID1);
  chMBFetch(&cr95hfMailbox, &message, TIME_INFINITE);
  if(rxbuf[0] == (msg_t)0x55) {
    // echo was a success, end function now
  } else {
    // throw an error here
  }
  memset(rxbuf, 0x00, sizeof(rxbuf));
}

void idle() {
  msg_t message;
  //////////////////////////////////////////////////////////////////////////
  // Temporary!
  // Remove before completing code!
  //////////////////////////////////////////////////////////////////////////
  uint8_t tempIdle[16] = {0x07, 0x0E, 0x02, 0x21, 0x00,  0x79, 0x01, 0x18, 0x00, 
                      0x01, 0x60, 0x60, 0x40, 0x50, 0x3F, 0x01};

  spiAcquireBus(&SPID1);
  spiSelect(&SPID1);
  spiSend(&SPID1, 1, &CR95HF_CMD);
  spiSend(&SPID1, 16, &tempIdle);//&idleCommand);
  spiUnselect(&SPID1);
  spiReleaseBus(&SPID1);
  chMBFetch(&cr95hfMailbox, &message, TIME_INFINITE);
  if(rxbuf[0] == 0x00) {
    if(rxbuf[1] == 0x01) {
      if(rxbuf[2] == 0x02) {
        // The idle command somehow changes how the IC communicates with tags.
        // So we reset the protocol before trying to talk to the tag again.
        setProtocol();
        sens_req();
        uint8_t nfcid[10];
        if(sdd_req(1, nfcid) == 1) {
          sel_req(1, 1, nfcid);
          if(sdd_req(2, nfcid) == 1) {
            sel_req(2, 1, nfcid);
            sdd_req(3, nfcid);
            sel_req(3, 0, nfcid);
          } else {
            sel_req(2, 0, nfcid);
          }
        } else {
          sel_req(1, 0, nfcid);
        }
        //uint8_t blocks[16];
        //type2Read(0x04, blocks);
        //uint8_t data[4] = {0xDE, 0xAD, 0xBE, 0xEF};
        //type2Write(0x04, data);
        //type2Read(0x04, blocks);
      }
    }
  }
  memset(rxbuf, 0x00, sizeof(rxbuf));
}
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

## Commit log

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2013-11-30 Added a few more components to the library and got about halfway done with the PoE power supply section.
    [rfidAndPOE.sch]
2013-11-30 Accidentally missed commiting the library and KiCAD project file.
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2013-12-05 Placed all of the components for the 5V isolated output from PoE.
    [rfidAndPOE.sch]
2013-12-06 Created a new resistor, diode, bridge rectifier, and capacitor schematic symbols. Default KiCAD ones were way too big.
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2013-12-06 Swapped out the bridge rectifier symbol on the schematic for one that is a normal size.
    [rfidAndPOE.sch]
2013-12-07 Added several test points for the PoE power supply. Also added a 5V test LED and a note about the isolated ground.
    [rfidAndPOE.sch]
2013-12-07 Forgot a current limiting resistor for the 5V test/power good LED. :)
    [rfidAndPOE.sch]
2013-12-07 Changed PVcc from a global flag to just a label and removed some of it's lines to make the schematic clearer.
    [rfidAndPOE.sch]
2013-12-07 Created a symbol for the RJ45 connector and hooked it up to the PoE stuff. Placed enc28j60, but haven't connected anything to it. May have added an extra library to the project file on accident.
    [rfidAndPOE.sch]
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2013-12-27 Added a test point and power good LED to the 3.3V rail.
    [rfidAndPOE.sch]
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2013-12-28 Added text to 12V supply and added a note about the 12V supply current limitations. Also relabeled some of the test points.
    [rfidAndPOE.sch]
2013-12-28 Missed the feedback connection to the IC in the 12V supply.
    [rfidAndPOE.sch]
2013-12-28 Fixed some wires that weren't actually connected.
    [rfidAndPOE.sch]
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2014-06-22 Had to change a bunch of parts in the schematic due to a KiCAD update. Rearranged ethernet termination resistors as well.
    [rfidAndPOE.sch]
2014-06-22 Pins from ethernet connector to PHY were flipped.
    [rfidAndPOE.sch]
2014-06-22 Connected passive to the ENC28J60. Only thing left for that is oscillator and connections to the micro.
    [rfidAndPOE.sch]
2014-06-22 Finished connecting up ENC28J60. Added a mems oscillator. Also commiting a new kicad related xml file.
    [rfidAndPOE.sch]
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2014-06-24 Added STM32F100RC to schematic. No connections to it yet. TODO: add 1uF capacitor to enc28j60.
    [rfidAndPOE.sch]
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2014-06-25 Added another bypass cap to the ENC28J60 power rail. Connected power rail of STM32F100RC/micro. Also added and connected programming connector and reset button to the micro.
    [rfidAndPOE.sch]
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2014-06-27 Added 24MHz oscillator to the micro.
    [rfidAndPOE.sch]
2014-06-27 Started schematic symbol for the RFID/NFC chip (CR95HF). Also added a note to check other symbols for belly pads. Almost forgot to do that!
    [rfidAndPOE.sch]
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2014-07-07 Fixed resistor having flipped reference and value. Also annotated schematic.
    [rfidAndPOE.sch]
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2014-07-15 Added two connectors to break out ports B and C on the microcontroller just in case.
    [rfidAndPOE.sch]
2014-07-15 Fixed spelling error in local net name.
    [rfidAndPOE.sch]
2014-07-15 Removed reminder to check for solder pads on ICs. Checked everything and all are correct.
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2014-07-15 Apparently missed the annotation of the two microcontroller port connectors.
    [rfidAndPOE.sch]
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2014-07-22 Added a revised SOD-523 footprint that has a cathode band on the silkscreen and the pins numbers are swapped to match KiCAD symbol conventions (1 for anode, 2 for cathode).
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2014-07-22 Changed TLV431 schematic symbol pin numbers to match SOT23 standard pin numbers.
    [rfidAndPOE.sch]
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2014-07-22 Created 2.5mmx2mm footprint for Si501 oscillators and associated it to the two oscillators on the board.
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2014-08-08 Added connector and transistor for external, switchable 12v output. Also reassigned some SMD package footprints that were renamed.
    [rfidAndPOE.sch]
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2014-08-09 Added missing wire junction in 12v transistor switch. Also updated some more footprints that had changed names (all are now updated).
    [rfidAndPOE.sch]
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2014-08-09 Updated solder mask clearance/min size.
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2014-08-10 Created new symbol for Si3440 transistor as well as TSOP-6 footprint. Assigned footprint to part.
    [rfidAndPOE.sch]
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2014-08-10 Pin assignment for Si3440DV transistor back annotated to schematic and was not commited.
    [rfidAndPOE.sch]
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2014-08-11 Moved ethernet port in to position and started routing some of the PoE stuff. Started moving other components near where they may end up going.,
    [rfidAndPOE.kicad_pcb]
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2014-08-12 Got some of the ethernet routing in place (50 ohm terminators, en28j60). Moved a bunch of the flyback circuitry in place and routed some of it.
    [rfidAndPOE.kicad_pcb]
2014-08-13 Moved the flyback transformer in to place as well as the switching transistor and supporting circuitry for that. Routed traces to them. Just the power good/feedback circuit left to place and route on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
    [rfidAndPOE.kicad_pcb]
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2014-08-14 Organized parts in to general sections (rest of PoE stuff, microcontroller, ethernet phy, 5v supply, and 3.3v supply are the groupings).
    [rfidAndPOE.kicad_pcb]
2014-08-15 Fixed a schematic error where the gate resistor for the 12v switch was not connected to anything. Finished placing flyback feedback parts and almost routed all of them. Placed microcontroller parts j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
    [rfidAndPOE.kicad_pcb, rfidAndPOE.sch]
2014-08-25 Placed and routed most of the enc28j60 components. Moved TPS61175 (12v boost supply) and components in to good orientation. Almost ready to route. Added ground plane on most of the board.
    [rfidAndPOE.kicad_pcb]
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2014-08-25 Routed 5V to switch mode supplies and routed 3.3v to ethernet chip.
    [rfidAndPOE.kicad_pcb]
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2014-08-25 Routed the last traces! Included a preview image of the final pcb.
    [rfidAndPOE.kicad_pcb]
2014-08-26 Added OSHW logo (should really be OHW), url for github repo, my name, and number identifiers for each board layer.
    [rfidAndPOE.kicad_pcb]
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2014-08-26 capacitor on input of PoE had one pad off of the board a little bit. Moved inwards.
    [rfidAndPOE.kicad_pcb]
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2014-08-26 Updated a bunch of silkscreen sizes and positions to make things look a little better.
    [rfidAndPOE.kicad_pcb]
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2014-08-30 Had to adjust size of vias and placement of silkscreen for manufacturing.
    [rfidAndPOE.kicad_pcb]
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2014-09-14 Renamed rfidAndPOE stuff to just POE since rfid board will be separate.
    [POE.kicad_pcb, POE.sch]
2014-09-14 Started rfid board project file and added cr95hf symbol to schematic to start.
    [rfid.sch]
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2014-09-17 Finished doing suggested pull ups, grounding, etc of certain pins. Added six pin connector for comms to micro. Not yet connected.
    [rfid.sch]
2014-09-18 Added a few extra 3.3k resistors from 3V3 to pins just in case. They are in the demo board so I am guessing I should include them.
    [rfid.sch]
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2014-09-22 Annotated schematic, generated netlist, and assigned footprints to all of the passives. Only connectors, IC, and crystal footprints have to be made and assigned.
    [rfid.sch]
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2014-09-22 CR95HF schematic symbol had the belly pad labeled as ~. Changed to 33 and updated schematic, netlist, library, etc.
    [rfid.sch]
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2014-09-22 Plus and minus symbols on back of board by PoE bridge rectifiers were reversed.
    [POE.kicad_pcb]
2014-09-24 Updated info about board issues.
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2014-09-29 Shorted resistor attached to antenna in schematic like the antenna basically will (to prevent DRC errors). Also renamed the crystal from X1 to G1.
    [rfid.kicad_pcb, rfid.sch]
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2014-09-29 Finished making sure all references are the correct size and moving them in to good locations.
    [rfid.kicad_pcb]
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2014-09-29 Thought that the correct phrase was OHW when it is actually OSHW. Updated board and gerbers to reflect this.
    [rfid.kicad_pcb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]
2014-09-29 A few vias weren't connected to the ground net, fixed that. Also added a zipped up version of the gerbers that were sent to oshpark.
    [rfid.kicad_pcb]
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2014-10-04 Moved plus and minus sign on POE bridge rectifier test points a handful of commits ago. Didn't actually need to so I swapped them back again.
    [POE.kicad_pcb]
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2014-10-06 Changed C5 to connect it to GNDA instead of VPortN. See http://jonneal.me/error-in-linear-tech-design-note-361/ for reason why.
    [POE.kicad_pcb, POE.sch]
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2015-01-30 Fixed pin 3 mode type so that it actually outputs a signal.
    [main.c]
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2015-03-11 Random stuff. Not working currently.
    [main.c]
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2015-03-20 Chaning compiler flag because LTO doesn't work with gcc 4.8 \(switched to linaro toolchain in between commits\).
2015-03-24 Removed compile time optimization as it was causing issues. Flipped around pin input/output definitions. Oops.
    [cr95hf_driver.c]
2015-03-24 SPI init now works and changed delays to the correct function.
    [cr95hf_driver.c, main.c]
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2015-03-26 Removed ISR locks that were causing bugs. Enabled full debugging. Mailboxes now working fun!
    [cr95hf_driver.c]
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2015-04-02 Move around some code bits for planning. Also clear some variables to prevent bugs.
    [cr95hf_driver.c]
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2015-04-18 Trying to figure out bug with the driver sending a read command without and interrupt telling it to do so.
    [cr95hf_driver.c]
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2015-04-21 Removed autostart from EXT interrupt driver. I was getting spurious interrupts from enabling the interrupt channel too early. Reverting interrupt function to how it was before debugging.
    [cr95hf_driver.c, main.c]
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2015-05-03 Figured out why I could not talk to NFC tags after putting the CR95HF in the idle state. Setting protocol after idle fixes this issue.
    [cr95hf_driver.c]
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2015-11-21 Switch to openocd for programming board, switch around a few pins numbers that are correct for the actual board.
    [main.c]
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2015-11-21 Quite a handful of changes to the POEstamp hardware as a start: * Removed all of the extra components from copying the POE files. * Fixed a couple of incorrect components in the schematic. * Fixed th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
    [POE.sch]
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2015-11-21 Finished adding BOM info to schematic. Swapped around a couple more symbols and footprints. Ran DRC and corrected one error.
    [POE.sch]
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2015-11-21 Added note about replacing components in the non isolated side due to thermal issues.
    [POE.sch]
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2015-11-22 Fixed backwards LED and finished putting all components within the board outline. Everything should be close to its final location, all silk screens are aligned pretty alright.
    [POE.kicad_pcb, POE.sch]
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

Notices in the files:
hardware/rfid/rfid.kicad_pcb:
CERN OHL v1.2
